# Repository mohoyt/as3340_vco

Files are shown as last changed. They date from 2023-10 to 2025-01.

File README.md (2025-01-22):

# AS3340 Voltage Controlled Oscillator
A Eurorack VCO powered by AS3340

## Features
* 40mm x 99mm single PCB design (so very cheap to manufacture)
* Lots of standing resistors and diodes to help achieve this (so it's a super crowded PCB)
* See BOM info [here](bom/ibom.html)

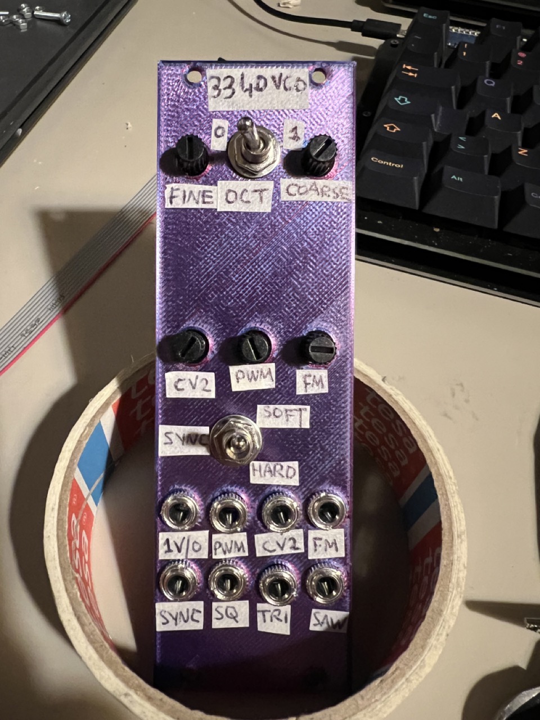
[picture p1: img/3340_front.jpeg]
front Module front


## Inputs
* 1v/Oct In
* CV2 In
* FM In
* Sync In (selectable between hard and soft sync with switch and settable between positive hard sync (default) and negative hard sync with a jumper)
* PWM Control In

## Outputs
* Sawtooth
* Square
* Triangle

## Influences
* [Digisound 80 VCO](http://www.digisound80.co.uk/digisound/modules/80-2_files/80-2.pdf)
* [Eddy Bergman's 3340 VCO](https://www.eddybergman.com/2020/01/synthesizer-build-part-18-really-good.html)
* [AI Synthesis' VCO](https://aisynthesis.com/product/ai011-voltage-controlled-oscillator/)

## Status
* First batch of PCBs arrived and 1 built. Working and tunable. 
* Lots of standing resistors to maximise soldering challenges
* 3d printed panel designed (now available in panels folder)
* Use this design at your own risk

## Build notes
* Pay close attention to the iBOM to get the right positioning
* Make sure you do the components under the ICs before you solder the IC sockets
* Start with the shorter components and work your way up (I started with resistors and diodes)
* Do panel components last (and ideally mount on panel before soldering to get best alignment)
* The digisound guide was helpful in tuning. Focus on getting the relationship between 1v/octave at lowish freqs with trimmer 2 while octave switch is off. Then use trimmer 1 to tune with keyboard with the fine tune pot in the middle position. Trimmer 3 can be used to adjust linearity at high freqs. 

## Known Issues
- [x] Some resistor values need updating in BOM
- [ ] Holes for toggle switches are slightly too close together so legs will need bent to fit until footprint is updated. 
- [ ] Footprint for poly timing cap could be much bigger

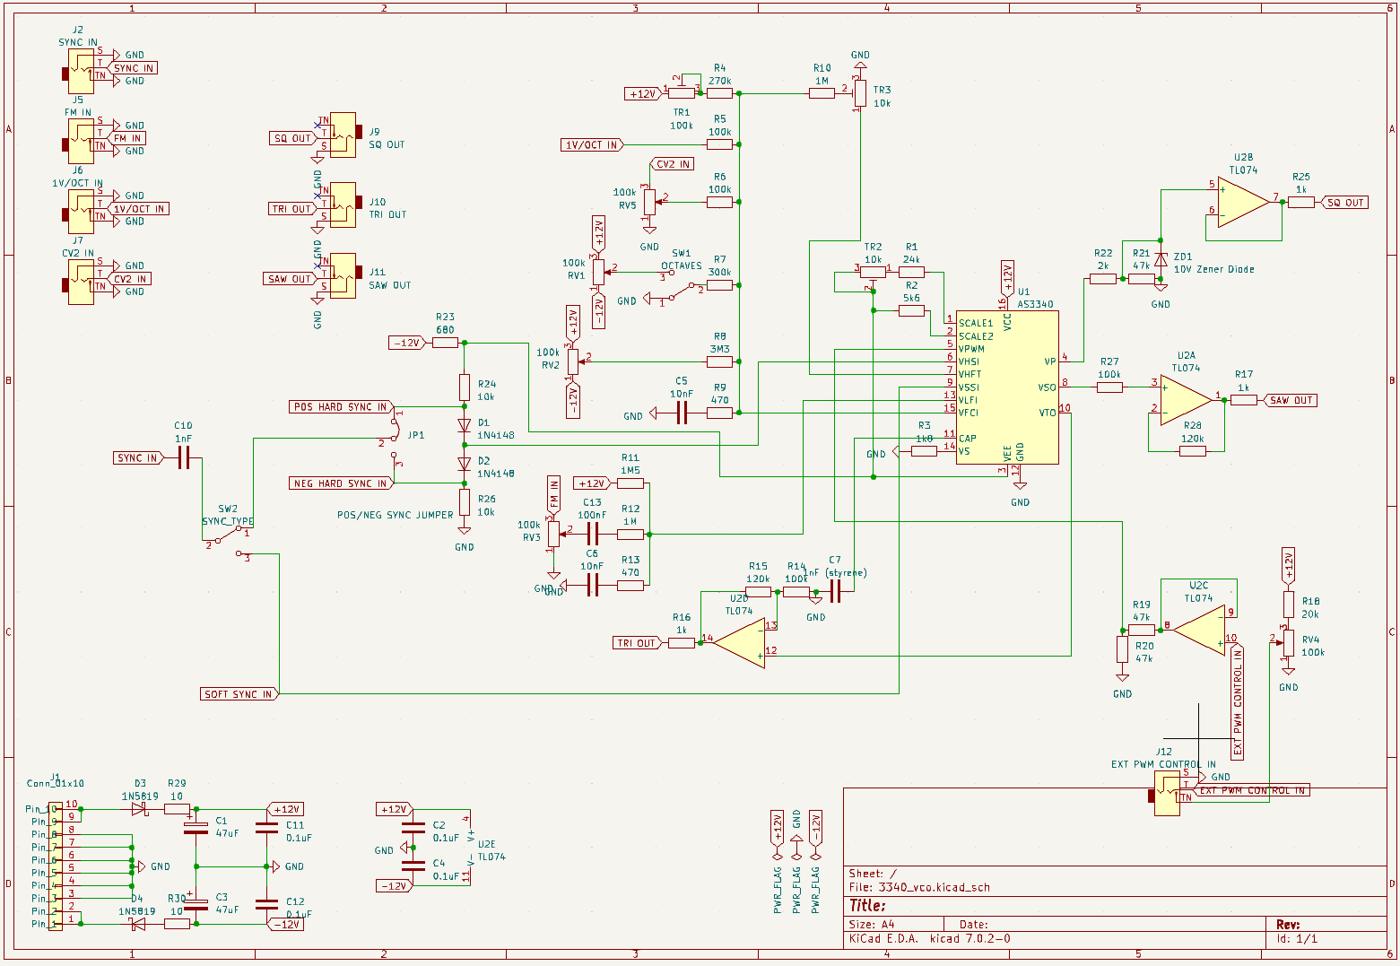
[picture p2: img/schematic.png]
schematic


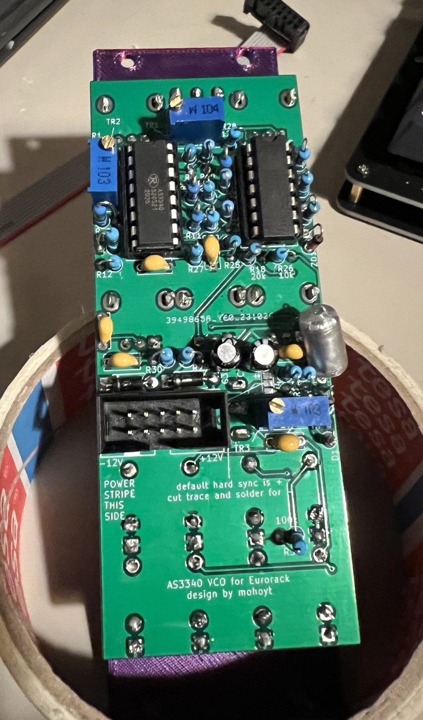
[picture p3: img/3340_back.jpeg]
back Module back


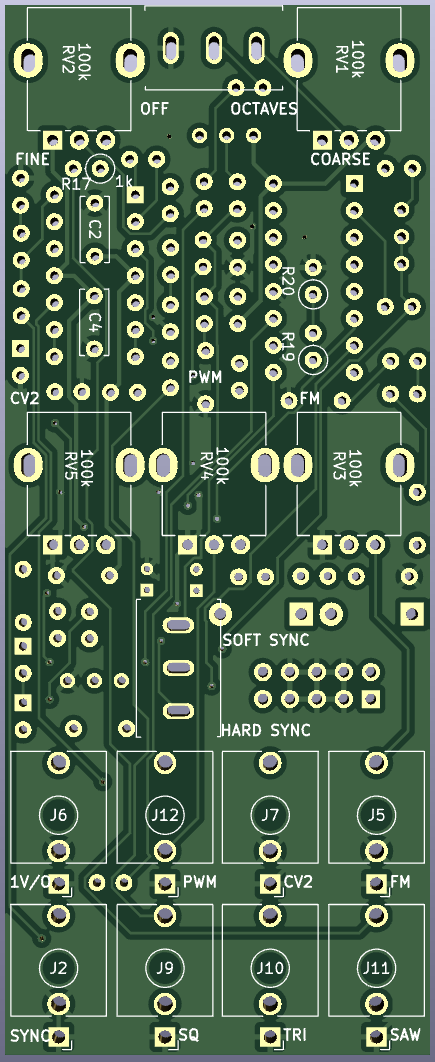
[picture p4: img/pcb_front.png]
PCB front


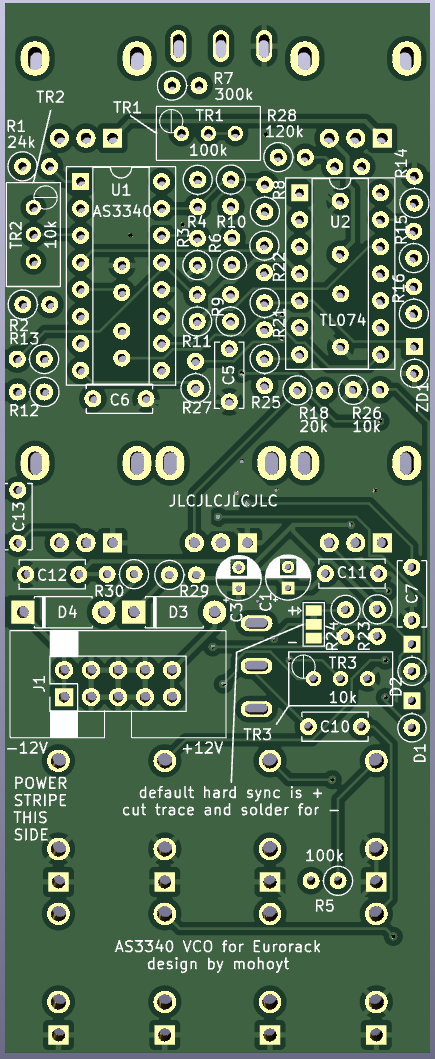
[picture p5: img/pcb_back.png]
PCB back


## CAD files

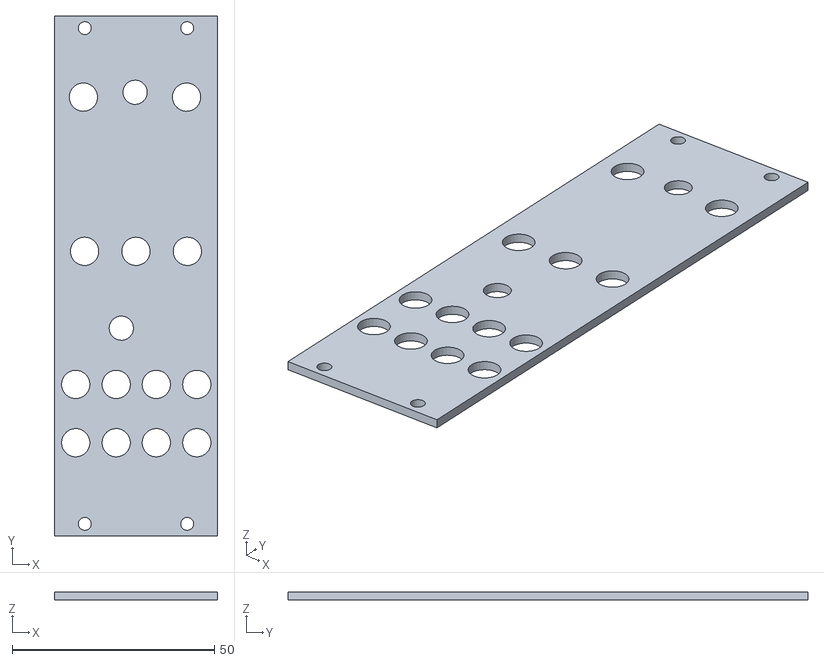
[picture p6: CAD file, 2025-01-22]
panel/3340 VCO.stl
40.3 x 128.5 x 2.00

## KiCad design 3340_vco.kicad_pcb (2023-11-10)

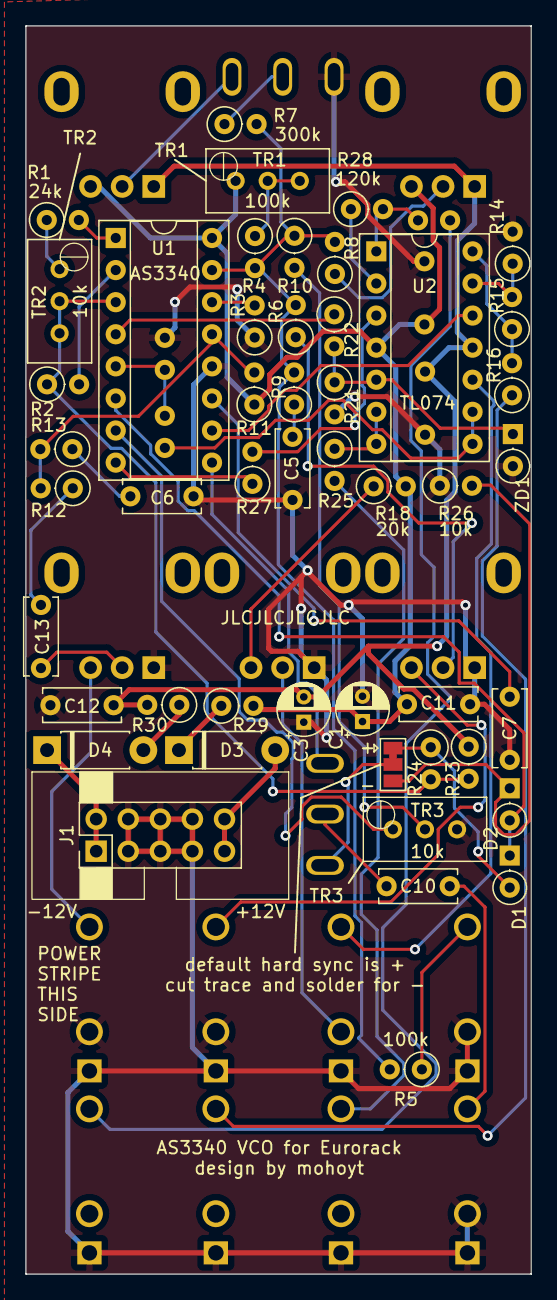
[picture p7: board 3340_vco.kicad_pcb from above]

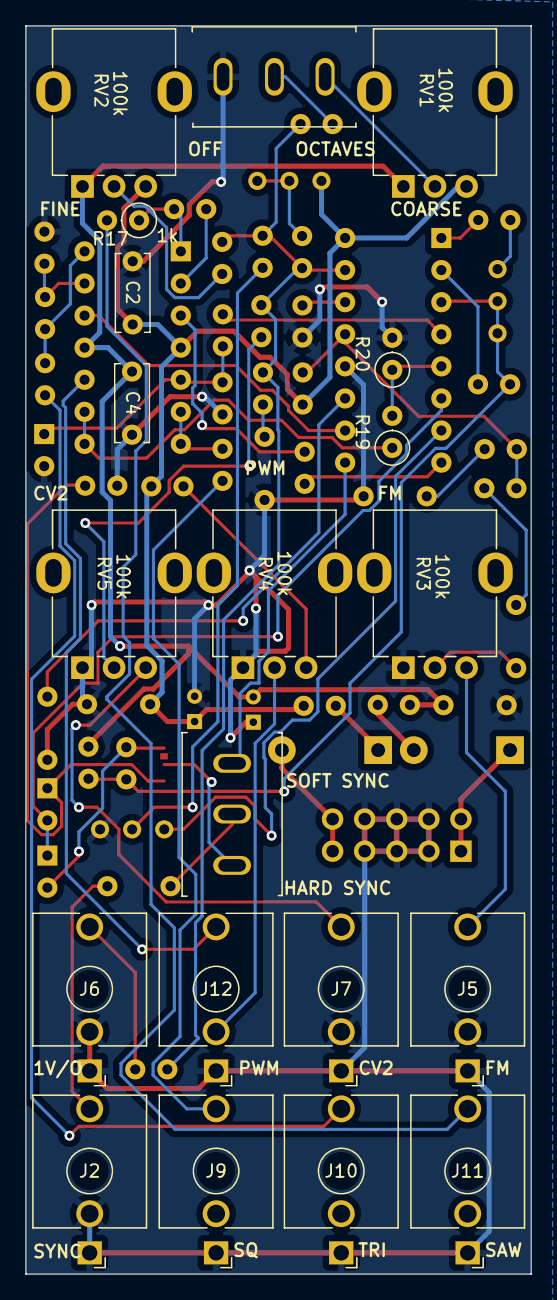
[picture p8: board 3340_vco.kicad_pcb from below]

Board: 2 copper layers, 40.0 x 98.8 mm, 68 parts (20 on the bottom side), 54 nets.

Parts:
C1, C3: 47uF; CP_Radial_D4.0mm_P2.00mm
C2, C4, C11, C12: 0.1uF; C_Disc_D6.0mm_W2.5mm_P5.00mm
C5, C6: 10nF; C_Disc_D6.0mm_W2.5mm_P5.00mm
C7: 1nF (styrene); C_Disc_D6.0mm_W2.5mm_P5.00mm
C10: 1nF; C_Disc_D6.0mm_W2.5mm_P5.00mm
C13: 100nF; C_Disc_D6.0mm_W2.5mm_P5.00mm
D1, D2: 1N4148; D_DO-35_SOD27_P2.54mm_Vertical_KathodeUp
D3, D4: 1N5819; D_DO-41_SOD81_P7.62mm_Horizontal
J1: Conn_01x10; PinHeader_2x05_P2.54mm_Vertical_Shroud
J2: SYNC IN; Jack_3.5mm_QingPu_WQP-PJ398SM_Vertical_CircularHoles
J5: FM IN; Jack_3.5mm_QingPu_WQP-PJ398SM_Vertical_CircularHoles
J6: 1V/OCT IN; Jack_3.5mm_QingPu_WQP-PJ398SM_Vertical_CircularHoles
J7: CV2 IN; Jack_3.5mm_QingPu_WQP-PJ398SM_Vertical_CircularHoles
J9: SQ OUT; Jack_3.5mm_QingPu_WQP-PJ398SM_Vertical_CircularHoles
J10: TRI OUT; Jack_3.5mm_QingPu_WQP-PJ398SM_Vertical_CircularHoles
J11: SAW OUT; Jack_3.5mm_QingPu_WQP-PJ398SM_Vertical_CircularHoles
J12: EXT PWM CONTROL IN; Jack_3.5mm_QingPu_WQP-PJ398SM_Vertical_CircularHoles
JP1: POS/NEG SYNC JUMPER; SolderJumper-3_P1.3mm_Bridged12_Pad1.0x1.5mm
R1: 24k; R_Axial_DIN0207_L6.3mm_D2.5mm_P2.54mm_Vertical
R2: 5k6; R_Axial_DIN0207_L6.3mm_D2.5mm_P2.54mm_Vertical
R3: 1k8; R_Axial_DIN0207_L6.3mm_D2.5mm_P2.54mm_Vertical
R4: 270k; R_Axial_DIN0207_L6.3mm_D2.5mm_P2.54mm_Vertical
R5, R6, R14, R27: 100k; R_Axial_DIN0207_L6.3mm_D2.5mm_P2.54mm_Vertical
R7: 300k; R_Axial_DIN0207_L6.3mm_D2.5mm_P2.54mm_Vertical
R8: 3M3; R_Axial_DIN0207_L6.3mm_D2.5mm_P2.54mm_Vertical
R9, R13: 470; R_Axial_DIN0207_L6.3mm_D2.5mm_P2.54mm_Vertical
R10, R12: 1M; R_Axial_DIN0207_L6.3mm_D2.5mm_P2.54mm_Vertical
R11: 1M2; R_Axial_DIN0207_L6.3mm_D2.5mm_P2.54mm_Vertical
R15, R28: 120k; R_Axial_DIN0207_L6.3mm_D2.5mm_P2.54mm_Vertical
R16, R17, R25: 1k; R_Axial_DIN0207_L6.3mm_D2.5mm_P2.54mm_Vertical
R18: 20k; R_Axial_DIN0207_L6.3mm_D2.5mm_P2.54mm_Vertical
R19, R20, R21: 47k; R_Axial_DIN0207_L6.3mm_D2.5mm_P2.54mm_Vertical
R22: 2k; R_Axial_DIN0207_L6.3mm_D2.5mm_P2.54mm_Vertical
R23: 680; R_Axial_DIN0207_L6.3mm_D2.5mm_P2.54mm_Vertical
R24, R26: 10k; R_Axial_DIN0207_L6.3mm_D2.5mm_P2.54mm_Vertical
R29, R30: 10; R_Axial_DIN0207_L6.3mm_D2.5mm_P2.54mm_Vertical
RV1, RV2, RV3, RV4, RV5: 100k; Potentiometer_Alpha_RD901F-40-00D_Single_Vertical
SW1: OCTAVES; SW_SPST_SPDT
SW2: SYNC_TYPE; SW_SPST_SPDT
TR1: 100k; Potentiometer_Bourns_3296W_Vertical
TR2, TR3: 10k; Potentiometer_Bourns_3296W_Vertical
U1: AS3340; DIP-16_W7.62mm_Socket
U2: TL074; DIP-14_W7.62mm_Socket
ZD1: 10V Zener Diode; D_DO-35_SOD27_P2.54mm_Vertical_KathodeUp

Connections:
1V/OCT IN: J6.T, R5.1
+12V: C1.1, C2.1, C11.1, R11.1, R18.2, R29.2, RV1.3, RV2.3, TR1.1, U1.16 (VCC), U2.4 (V+)
-12V: C3.2, C4.2, C12.2, R23.1, R30.2, RV1.1, RV2.1, U2.11 (V-)
CV2 IN: J7.T, RV5.3
EXT PWM CONTROL IN: J12.T, U2.10 (+)
FM IN: J5.T, RV3.3
GND: C1.2, C2.2, C3.1, C4.1, C5.1, C6.1, C7.1, C11.2, C12.1, J1.3, J1.4, J1.5, J1.6, J1.7, J1.8, J2.S, J2.TN, J5.S, J5.TN, J6.S, J6.TN, J7.S, J7.TN, J9.S, J10.S, J11.S, J12.S, R3.1, R14.2, R20.2, R21.2, R26.1, RV3.1, RV4.1, RV5.1, SW1.1 (A), TR3.3, U1.12 (GND), ZD1.2 (A)
NEG HARD SYNC IN: D2.1 (K), JP1.3 (B), R26.2
unnamed: C5.2, R9.1
unnamed: C6.2, R13.1
unnamed: C13.1, RV3.2
unnamed: C13.2, R12.1
unnamed: D1.1 (K), D2.2 (A), U1.6 (VHSI)
unnamed: D3.2 (A), J1.9, J1.10
unnamed: D3.1 (K), R29.1
unnamed: D4.2 (A), R30.1
unnamed: D4.1 (K), J1.1, J1.2
unnamed: J12.TN, RV4.2
unnamed: JP1.2 (C), SW2.1 (A)
unnamed: R1.1, TR2.1
unnamed: R4.1, TR1.2, TR1.3
unnamed: R6.1, RV5.2
unnamed: R8.1, RV2.2
unnamed: R10.2, TR3.2
unnamed: R15.1, R16.2, U2.14
unnamed: R17.1, R28.2, U2.1
unnamed: R18.1, RV4.3
unnamed: R7.1, SW1.2 (B)
unnamed: RV1.2, SW1.3 (C)
unnamed: C10.2, SW2.2 (B)
unnamed: C7.2, U1.11 (CAP)
unnamed: R1.2, U1.1 (SCALE1)
unnamed: R2.2, U1.2 (SCALE2)
unnamed: R2.1, R23.2, R24.2, TR2.2, TR2.3, U1.3 (VEE)
unnamed: R4.2, R5.2, R6.2, R7.2, R8.2, R9.2, R10.1, U1.15 (VFCI)
unnamed: TR3.1, U1.7 (VHFT)
unnamed: R11.2, R12.2, R13.2, U1.13 (VLFI)
unnamed: R22.1, U1.4 (VP)
unnamed: R19.2, R20.1, U1.5 (VPWM)
unnamed: R3.2, U1.14 (VS)
unnamed: R27.1, U1.8 (VSO)
unnamed: U1.10 (VTO), U2.12 (+)
unnamed: R27.2, U2.3 (+)
unnamed: R28.1, U2.2 (-)
unnamed: R21.1, R22.2, U2.5 (+), ZD1.1 (K)
unnamed: R25.1, U2.6 (-), U2.7
unnamed: R19.1, U2.8, U2.9 (-)
unnamed: R14.1, R15.2, U2.13 (-)
POS HARD SYNC IN: D1.2 (A), JP1.1 (A), R24.1
SAW OUT: J11.T, R17.2
SOFT SYNC IN: SW2.3 (C), U1.9 (VSSI)
SQ OUT: J9.T, R25.2
SYNC IN: C10.1, J2.T
TRI OUT: J10.T, R16.1

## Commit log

2023-10-25 v1 added
    [3340_vco-B_Cu.gbl, 3340_vco-B_Mask.gbs, 3340_vco-B_Paste.gbp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]
2023-10-26 BOM added
2023-11-10 BOM updated with correct resistor values
    [3340_vco.kicad_pcb, 3340_vco.kicad_sch]
2025-01-22 3D printed panel added
    [3340 VCO.stl]
